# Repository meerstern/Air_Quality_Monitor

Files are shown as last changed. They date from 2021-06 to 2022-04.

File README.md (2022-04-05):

# エアクオリティモニタ 
 Air Quality Monitor with ZMOD4410 & HS3001

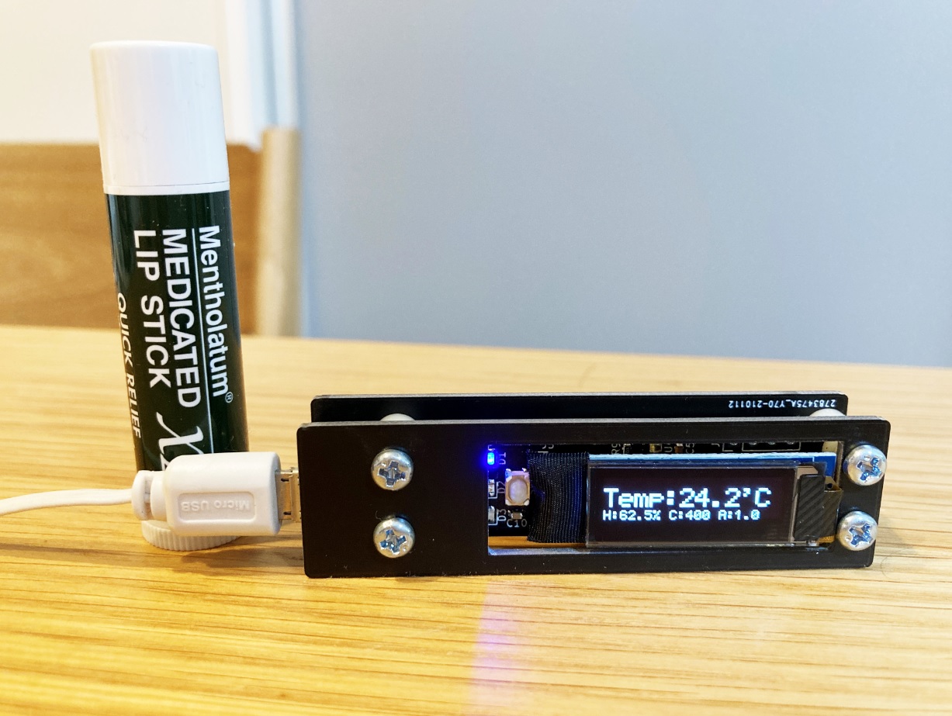
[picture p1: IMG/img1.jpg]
  
  ※ 写真は使用イメージです リップスティック、USBケーブル等は含まれません  

 ## 概要 
  *  [室内空気質（IAQ）センサZMOD4410][1]及び[温湿度センサHS3001][2]を搭載したエアクオリティモニタです 
  * スティック状の小型な本体にCO2値、IAQ(屋内空気質基準)、温度、湿度を表示することができます  
  * 電源はmicroUSBを介してUSB電源(5V/300mA)で駆動します  
  * CO2計算アルゴリズムはメーカ提供の学習済みニューラルネットワークを使用したファームウェアを使用しています  
  * 学習済みニューラルネットワークによって従来よりもより正確にCO2値（eCO2）を推定できます  
  * LEDでIAQ(屋内空気質基準IAQ:2以下 青、2-3:青、黄、3-4:黄、4-5:黄、赤、5以上:赤)を確認できます 
  * 過去10時間の推移をグラフで簡易的に確認することができます  
  * 寝室等での利用を想定し、周辺の明るさに応じてLEDとディスプレイの輝度が低下します  
  * ボタン切り替えでCO2表示モード、温度表示モード、湿度表示モード、IAQ表示モードの切り替えが可能です  

  |  項目  |  範囲  | 
| ---- | ---- | 
|  温度  |  -40-125℃  |   
|  湿度  |  0-100%RH  | 
|  CO2  |  400-5000ppm  |  
|  IAQ  |  1.0-5.0  |  
    
 ドイツ環境庁（UBA）の屋内空気質（IAQ）基準
 
  |  IAQ  |  レベル  |  LED  |
| ---- | ---- | ---- |
|  <2  |  非常に良い  |  青  |
|  2~3  |  良い  |  青と黄  |
|  3~4  |  中間  |  黄  |
|  4~5  |  悪い  |  黄と赤  |
|  5~  |  非常に悪い | 赤 |
    
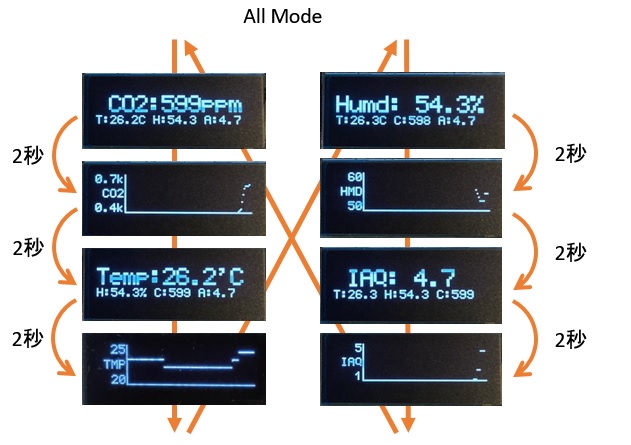
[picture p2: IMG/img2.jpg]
   

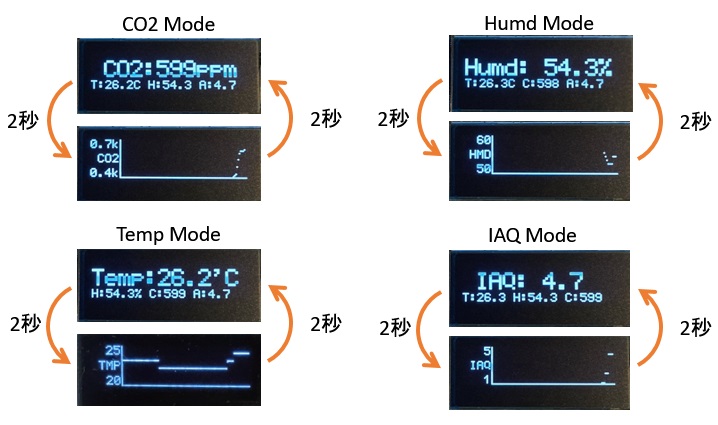
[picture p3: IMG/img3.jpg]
   
  
## 各部説明 
　
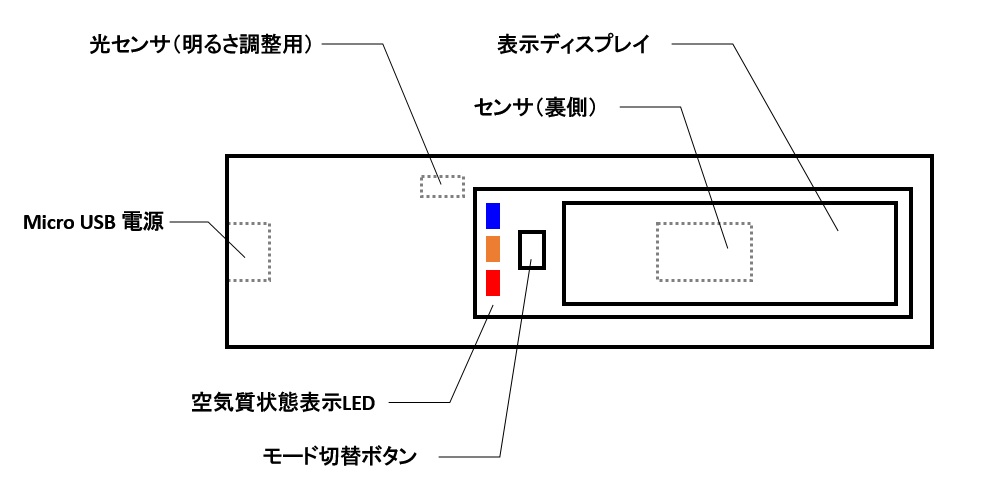
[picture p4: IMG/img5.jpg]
   
  　
## サイズ
　幅7.5cm × 高さ2cm × 奥行 1.5cm (突起部除く)

## 注意 
 * 本センサはMOX(Metal Oxide)式のCO2センサのため、空気中の有機物から間接的にCO2に換算します  
 * 厳密なCO2計測には向きません  
 * 安定した測定をするために人通りや気流の変化が少ない場所に設置して使用してください  
 * キャリブレーション後にCO2値が安定するまで約0.5~1時間程度要します  
 * IAQは総合的な空気質の指標のため、CO2値が低くても他の有機物が多い場合に高くなります  
 * 電源投入後、2~3分はキャリブレーションのため、温湿度以外の値は未定で、全LEDが点灯します  
 * 約2秒周期で各センサの値を取得します(データ更新時にLEDが点滅します)  
 * センサのデータ応答が異常な場合、自動的に再起動する場合があります  
 * 再起動した場合はグラフの履歴がリセットされます  
 * 告知なしに仕様を変更する場合があります   
 * 背面のセンサ穴を塞がないように設置してください   

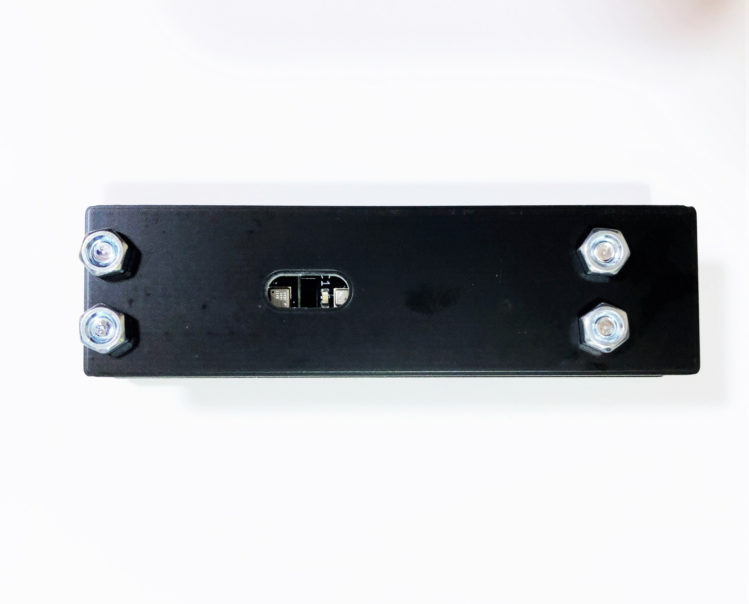
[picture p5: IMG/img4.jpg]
   
  
[1]: https://www.idt.com/jp/ja/products/sensor-products/gas-sensors/zmod4410-indoor-air-quality-sensor-platform
[2]: https://www.idt.com/us/ja/products/sensor-products/humidity-sensors/hs3001-high-performance-relative-humidity-and-temperature-sensor

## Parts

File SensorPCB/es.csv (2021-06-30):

ID | 参照記号 | パッケージ | 数 | 名称 | Supplier and ref
1 | U2 | ZMOD4410 | 1 | ZMOD4410
2 | R6 | R_0603_1608Metric | 1 | 10
3 | R2,R1 | R_0603_1608Metric | 2 | 4.7k
4 | REF2,REF1 | MountingHole_3.2mm_M3 | 2 | MountingHole_3.2mm_M3
5 | U1 | HS300X | 1 | HS300X
6 | TP1 | TestPoint_THTPad_D1.0mm_Drill0.5mm | 1 | TestPoint
7 | R3 | R_0603_1608Metric | 1 | 200k
8 | J1 | GROVE | 1 | Conn_01x04
9 | C5,C4,C3,C2,C1 | C_0603_1608Metric | 5 | 0.1u

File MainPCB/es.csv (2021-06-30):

ID | 参照記号 | パッケージ | 数 | 名称 | Supplier and ref
1 | REF4,REF3,REF2,REF1 | MountingHole_3.2mm_M3 | 4 | MountingHole_3.2mm_M3
2 | U2 | QFN-32-1EP_5x5mm_P0.5mm_EP3.45x3.45mm | 1 | STM32F301K8Ux
3 | J2 | PinHeader_1x04_P2.54mm_Vertical | 1 | SWD
4 | U1 | SOT-23-5 | 1 | LD3985M33R_SOT23
5 | J3 | GROVE | 1 | SENSOR
6 | C3 | C_0603_1608Metric | 1 | 0.01u
7 | C2,C5,C6,C7,C8,C9,C10 | C_0603_1608Metric | 7 | 0.1u
8 | D1,D2,D3 | D_0603_1608Metric | 3 | LED
9 | J4 | PinHeader_1x03_P2.54mm_Vertical | 1 | Conn_01x03
10 | R1,R2 | R_0603_1608Metric | 2 | 10k
11 | R3,R4,R5 | R_0603_1608Metric | 3 | 1k
12 | F1 | Fuse_0603_1608Metric | 1 | Fuse
13 | J1 | GROVE | 1 | MPU
14 | M1 | CONN-10118194-0001LF-FCI | 1 | mUSB
15 | R6,R7 | R_0603_1608Metric | 2 | 27
16 | R8 | R_0603_1608Metric | 1 | 1.5k
17 | SW1 | SKRPACE010 | 1 | SW_Push
18 | U3 | SO-8_3.9x4.9mm_P1.27mm | 1 | PL2303SA
19 | J5 | PinHeader_1x04_P2.54mm_Vertical | 1 | OLED
20 | C1,C4 | C_0805_2012Metric | 2 | 2.2u
21 | R9 | R_0603_1608Metric | 1 | 4.7k
22 | U4 | APDS-9008 | 1 | APDS-9008

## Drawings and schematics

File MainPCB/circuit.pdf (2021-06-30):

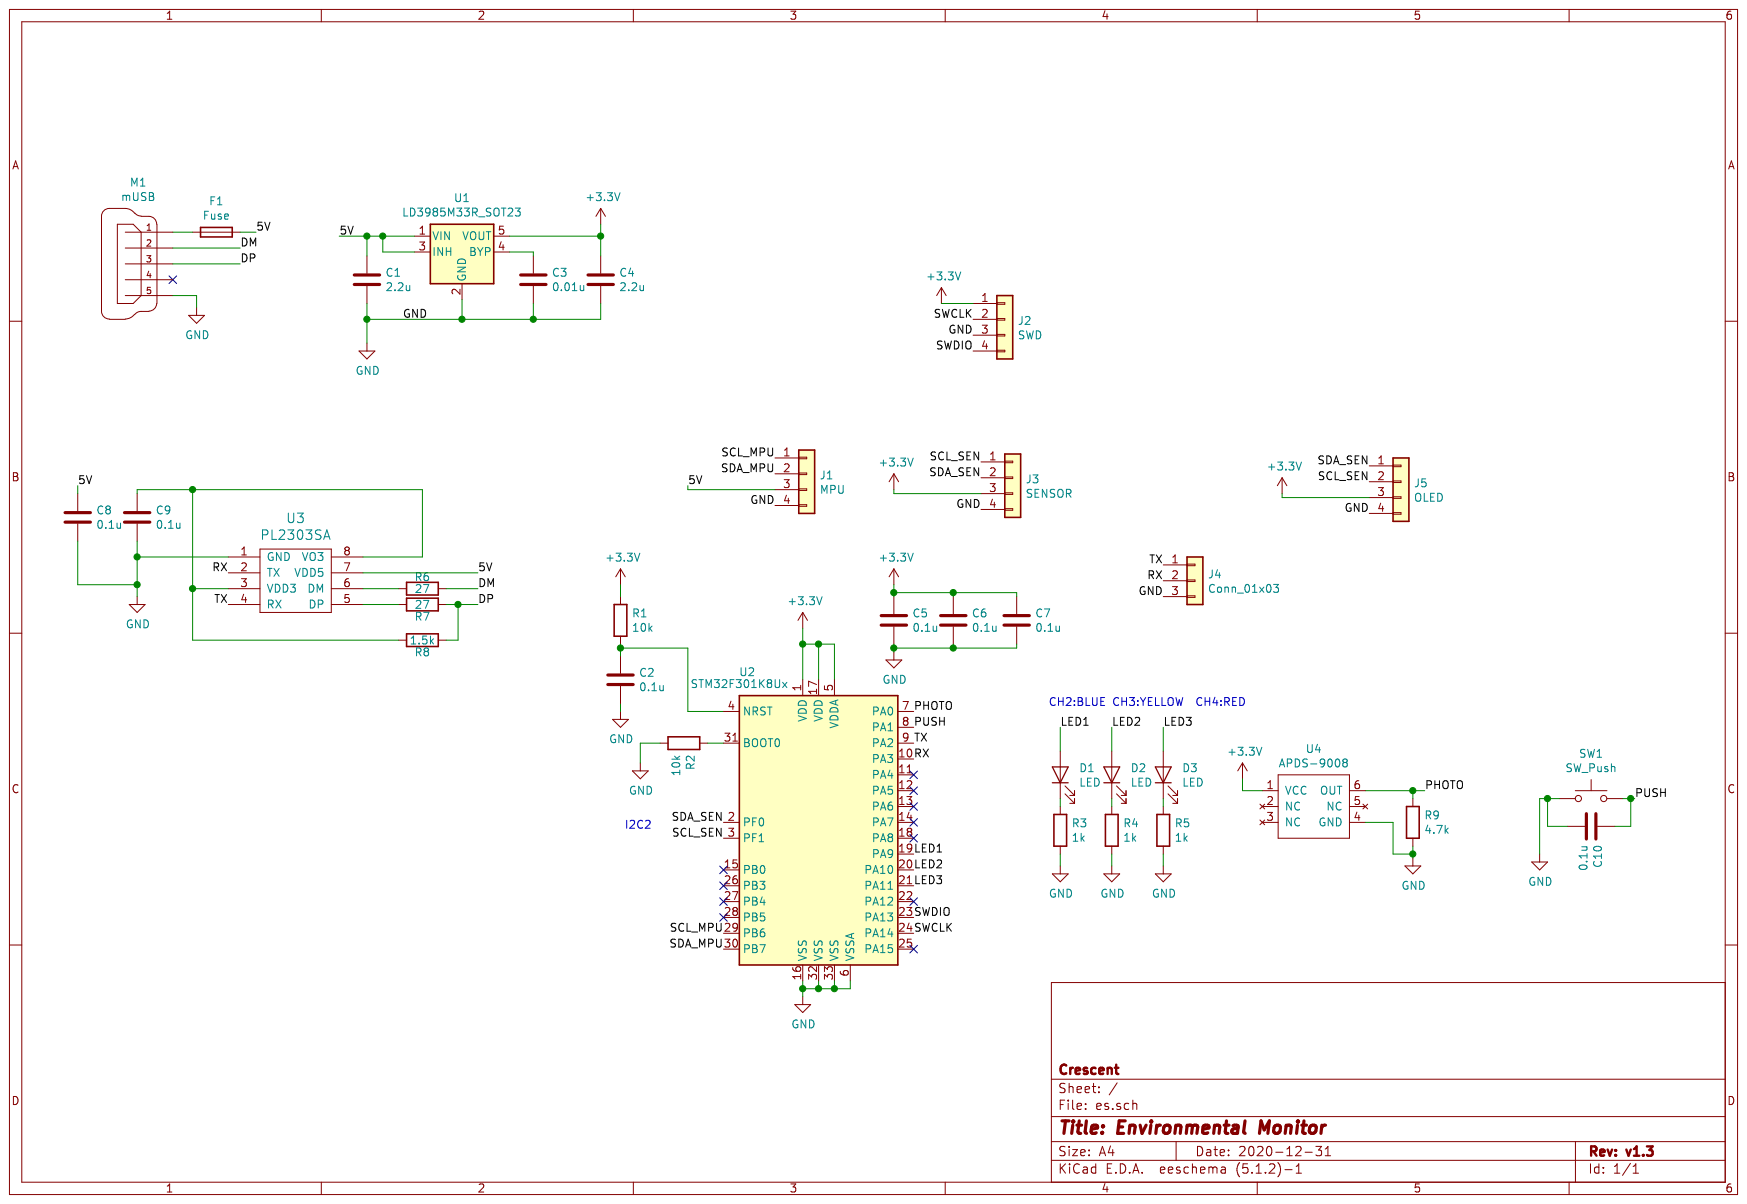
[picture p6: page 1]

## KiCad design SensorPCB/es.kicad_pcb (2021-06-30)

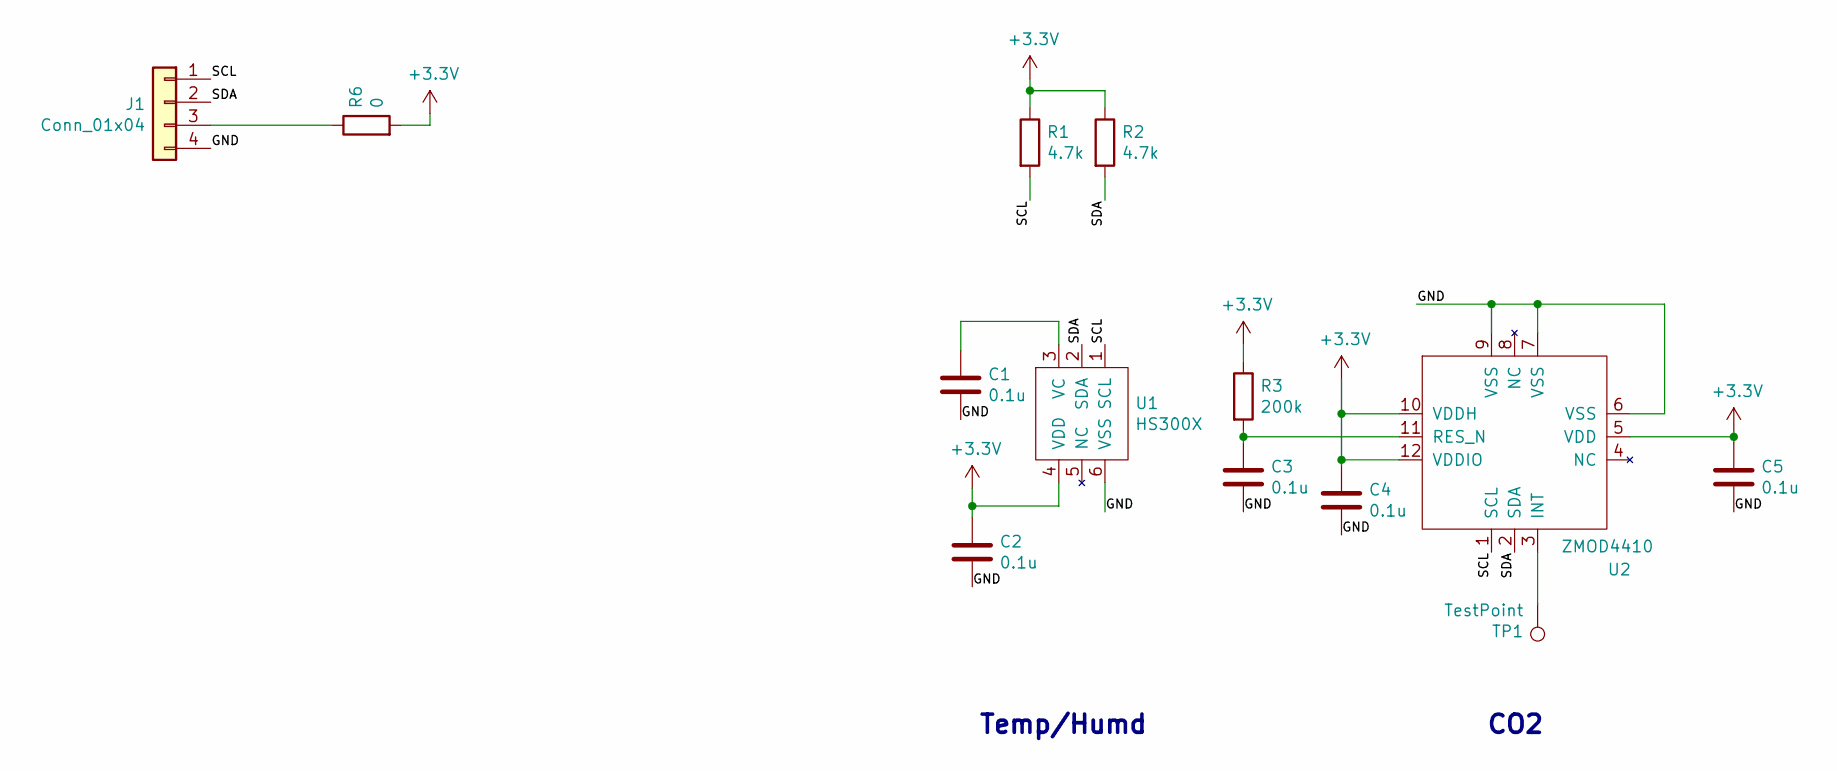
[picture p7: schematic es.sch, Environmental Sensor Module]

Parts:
C1, C2, C3, C4, C5: 0.1u; C_0603_1608Metric
J1: Conn_01x04; GROVE
R1, R2: 4.7k; R_0603_1608Metric
R3: 200k; R_0603_1608Metric
R6: 0; R_0603_1608Metric
TP1: TestPoint; TestPoint_THTPad_D1.0mm_Drill0.5mm
U1: HS300X
U2: ZMOD4410

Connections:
+3V3: C2.1, C4.1, C5.1, R1.1, R2.1, R3.1, R6.2, U1.4 (VDD), U2.5 (VDD), U2.10 (VDDH), U2.12 (VDDIO)
/GND: C1.2, C2.2, C3.2, C4.2, C5.2, J1.4, U1.6 (VSS), U2.6 (VSS), U2.7 (VSS), U2.9 (VSS)
/SCL: J1.1, R1.2, U1.1 (SCL), U2.1 (SCL)
/SDA: J1.2, R2.2, U1.2 (SDA), U2.2 (SDA)
unnamed: C1.1, U1.3 (VC)
unnamed: C3.1, R3.2, U2.11 (RES_N)
unnamed: J1.3, R6.1
unnamed: TP1.1, U2.3 (INT)

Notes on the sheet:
CO2
Temp/Humd

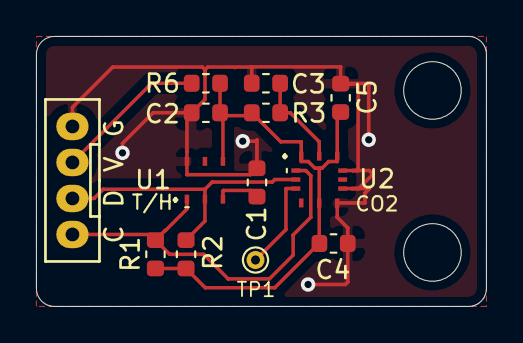
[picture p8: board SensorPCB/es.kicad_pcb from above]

Board: 2 copper layers, 25.0 x 15.0 mm, 15 parts (0 on the bottom side), 8 nets.

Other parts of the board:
REF1, REF2: MountingHole_3.2mm_M3

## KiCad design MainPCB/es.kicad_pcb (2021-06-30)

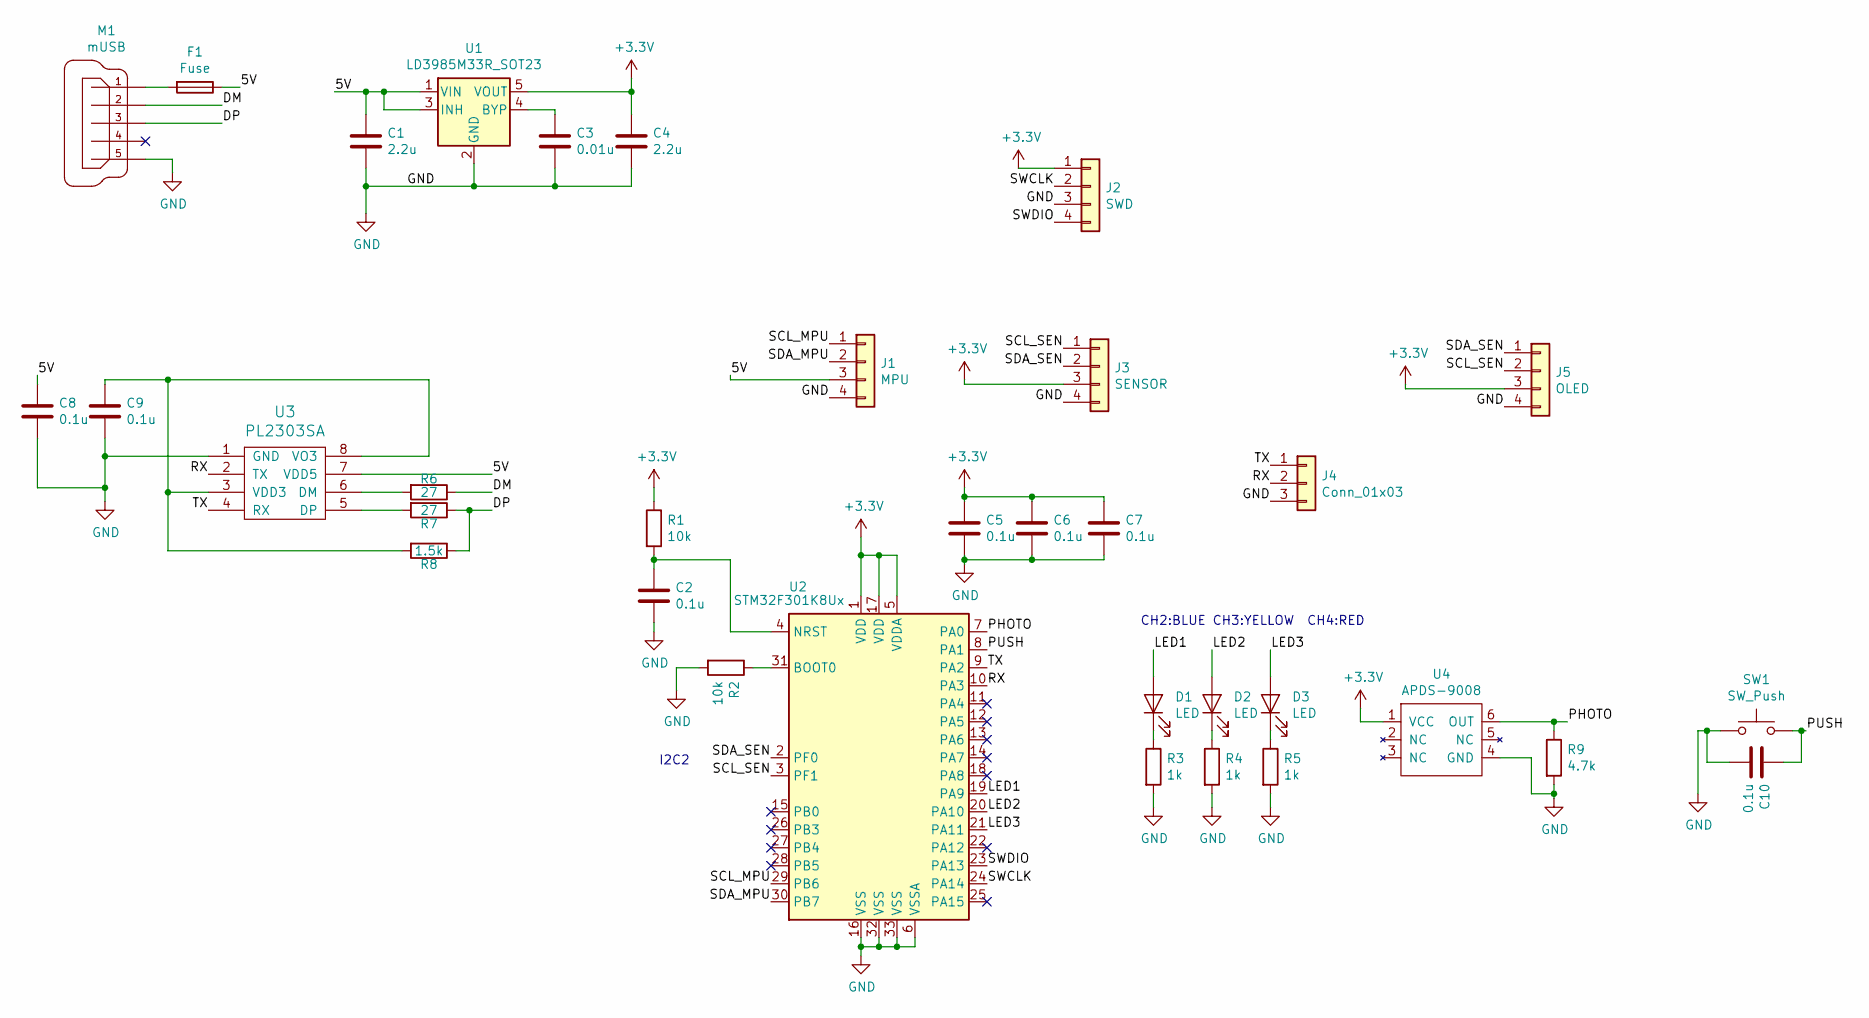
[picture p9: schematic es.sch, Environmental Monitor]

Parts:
C1, C4: 2.2u; C_0805_2012Metric
C2, C5, C6, C7, C8, C9, C10: 0.1u; C_0603_1608Metric
C3: 0.01u; C_0603_1608Metric
D1, D2, D3: LED; D_0603_1608Metric
F1: Fuse; Fuse_0603_1608Metric
J1: MPU; GROVE
J2: SWD; PinHeader_1x04_P2.54mm_Vertical
J3: SENSOR; GROVE
J4: Conn_01x03; PinHeader_1x03_P2.54mm_Vertical
J5: OLED; PinHeader_1x04_P2.54mm_Vertical
M1: mUSB; CONN-10118194-0001LF-FCI
R1, R2: 10k; R_0603_1608Metric
R3, R4, R5: 1k; R_0603_1608Metric
R6, R7: 27; R_0603_1608Metric
R8: 1.5k; R_0603_1608Metric
R9: 4.7k; R_0603_1608Metric
SW1: SW_Push; SKRPACE010
U1: LD3985M33R_SOT23; SOT-23-5
U2: STM32F301K8Ux; QFN-32-1EP_5x5mm_P0.5mm_EP3.45x3.45mm
U3: PL2303SA; SO-8_3.9x4.9mm_P1.27mm
U4: APDS-9008

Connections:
+3V3: C4.1, C5.1, C6.1, C7.1, J2.1, J3.3, J5.3, R1.1, U1.5 (VOUT), U2.1 (VDD), U2.5 (VDDA), U2.17 (VDD), U4.1 (VCC)
/5V: C1.1, C8.1, F1.1, J1.3, U1.1 (VIN), U1.3 (INH), U3.7 (VDD5)
/DM: M1.2, R6.1
/DP: M1.3, R7.1, R8.1
/LED1: D1.2 (A), U2.19 (PA9)
/LED2: D2.2 (A), U2.20 (PA10)
/LED3: D3.2 (A), U2.21 (PA11)
/PHOTO: R9.1, U2.7 (PA0), U4.6 (OUT)
/PUSH: C10.1, SW1.2, U2.8 (PA1)
/RX: J4.2, U2.10 (PA3), U3.2 (TX)
/SCL_MPU: J1.1, U2.29 (PB6)
/SCL_SEN: J3.1, J5.2, U2.3 (PF1)
/SDA_MPU: J1.2, U2.30 (PB7)
/SDA_SEN: J3.2, J5.1, U2.2 (PF0)
/SWCLK: J2.2, U2.24 (PA14)
/SWDIO: J2.4, U2.23 (PA13)
/TX: J4.1, U2.9 (PA2), U3.4 (RX)
GND: C1.2, C2.2, C3.2, C4.2, C5.2, C6.2, C7.2, C8.2, C9.2, C10.2, J1.4, J2.3, J3.4, J4.3, J5.4, M1.5, R2.2, R3.2, R4.2, R5.2, R9.2, SW1.1, U1.2 (GND), U2.6 (VSSA), U2.16 (VSS), U2.32 (VSS), U2.33 (VSS), U3.1 (GND), U4.4 (GND)
unnamed: C2.1, R1.2, U2.4 (NRST)
unnamed: C3.1, U1.4 (BYP)
unnamed: C9.1, R8.2, U3.3 (VDD3), U3.8 (VO3)
unnamed: D1.1 (K), R3.1
unnamed: D2.1 (K), R4.1
unnamed: D3.1 (K), R5.1
unnamed: F1.2, M1.1
unnamed: R2.1, U2.31 (BOOT0)
unnamed: R6.2, U3.6 (DM)
unnamed: R7.2, U3.5 (DP)

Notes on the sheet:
I2C2
CH2:BLUE
CH3:YELLOW
CH4:RED

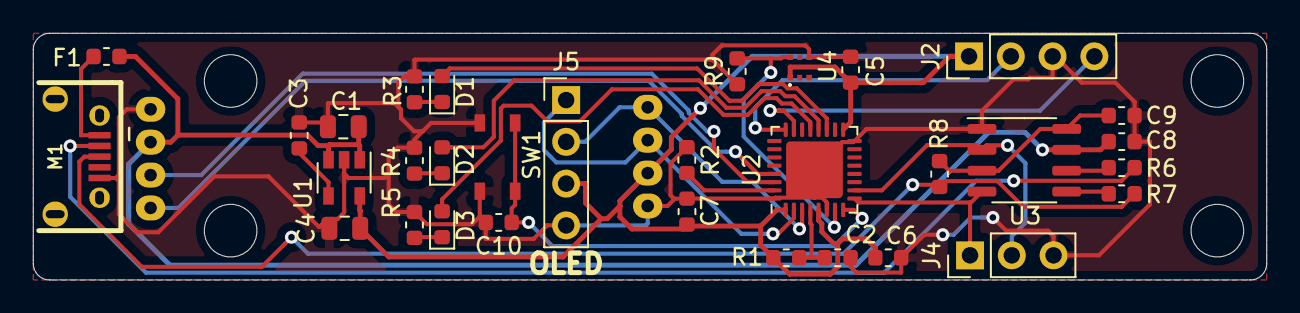
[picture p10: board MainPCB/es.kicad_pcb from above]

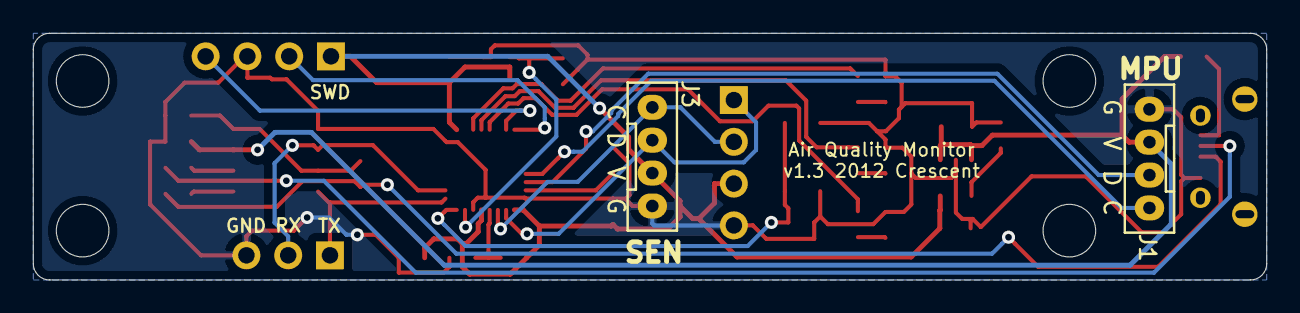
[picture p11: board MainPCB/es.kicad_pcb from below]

Board: 2 copper layers, 75.0 x 15.0 mm, 38 parts (2 on the bottom side), 28 nets.

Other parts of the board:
REF1, REF2, REF3, REF4: MountingHole_3.2mm_M3

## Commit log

2021-06-30 Add Main PCB Files
    [es-B_Cu.gbl, es-B_Mask.gbs, es-B_Paste.gbp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]
2021-06-30 Add Sensor PCB Files
    [es-B_Cu.gbl, es-B_Mask.gbs, es-B_Paste.gbp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]
